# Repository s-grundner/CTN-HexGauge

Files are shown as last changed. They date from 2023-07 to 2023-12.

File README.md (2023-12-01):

# (EN) Hex Gauge

Customizable Automotive Gauge with CAN Bus and Integrated Inertial Measurement Unit

This is one of the initial Car Telemetry Networking (CTN) Projects.

The goal is to establish a Network of IoT devices for automotive telemtry capturing.

## Latest Revision

| Components Side | Display Side |
|-|-|
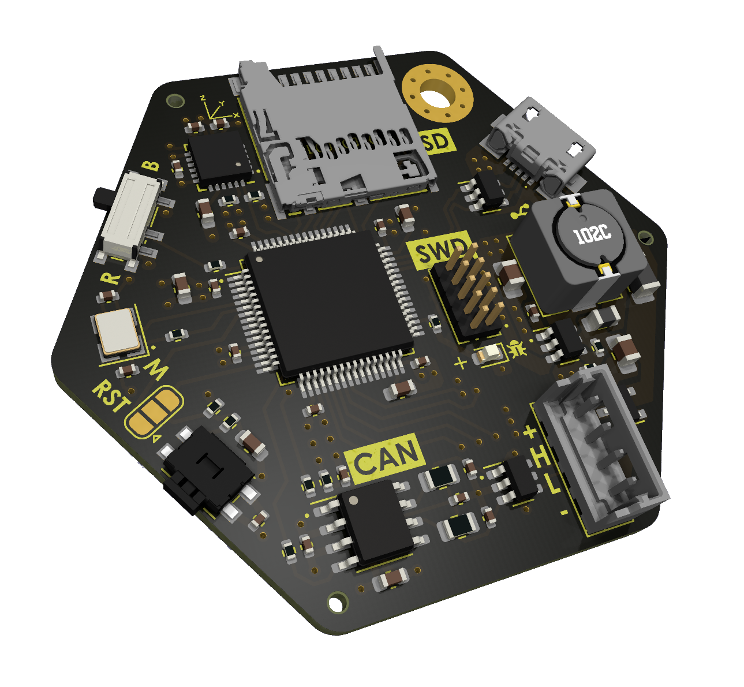
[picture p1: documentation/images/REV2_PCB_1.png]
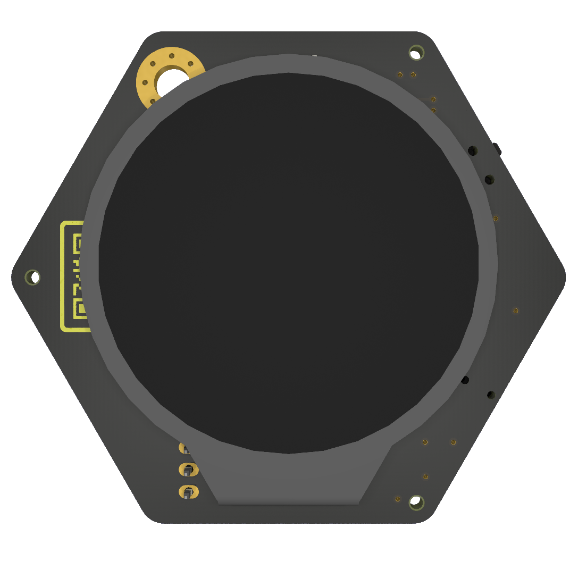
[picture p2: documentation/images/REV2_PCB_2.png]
|||

## Repository Structure

- [Documentation](/documentation/)
- [Manufacturing](/manufacturing/)
- [Simulations](/simulations/)
- [Source Code](/source/)

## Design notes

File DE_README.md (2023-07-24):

# (DE) Automobil Telemetrie Netzwerk

## Master Controller

| Nr  | Relevante Sensoren am Can bus | Instrumentenadresse/ID | Serienmäßig |
| --- | --- | --- | --- |
| 1 | Motordrehzahl | `0x` | ja |
| 2 | Geschwindigkeit | `0x` | ja |
| 3 | Reifendrehzahl | `0x` | ja |
| | | | |
| 4 | Batteriespannung | `0x` | ja |
| | | | |
| 5 | Öltemperatur | `0x` | ja |
| 6 | Kühlfl. Temperatur | `0x` | ja |
| 13  | Reifentemparatur | `0x` | nein |
| | | | |
| 7 | Öldruck | `0x` | ja |
| 8 | Bremsdruck | `0x` | ja |
| 9 | Kraftstoffdruck | `0x` | ja |
| | | | |
| 10  | Gaspedalposition | `0x` | ja |
| 11  | Gyroskop | `0x` | nein |

### Berechnungen

- CAN Bus Interface mit uC
  - Codes Auslesen
  - Ausgelesene Codes auf Armaturen schreiben

- Bremsschwund Erkennung und Berechnung
  - Vergleicht Bremsleitungsdruck mit Entschleunigung
  - Zeichnet Werte bei Verschiedenen Geschwindigkeiten auf und vergleicht

## Funktionseinheiten

### Reifentemaparatursensor

### Gyroskop

### Drehzahl LED-Leiste

## Modulare Hex Armaturen

- Ein zentrales Master Instrument, wo die Daten eingespeist werden (Drahtlos/Verdrahtet)
- Bus erweiterungen an 2/3/6 seiten des Hexagons
- Instrumentenadresse mit DIP-Schaltern einstellbar (SC18IS602B)
  - ID bestimmt angezeigte Daten
  - ID wird in SPI Chipselect konvertiert

## Retro Bargraphs

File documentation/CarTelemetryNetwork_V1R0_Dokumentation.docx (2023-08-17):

# Car Telemetry Network

# [Betreff]

Projekt Dokumentation – [DE]

Autor: Simon Grundner

V1R0

01/08/2023

# 1. H1

## 1.1 H2

### 1.1.1 H3

#### 1.1.1.1 H4

Simon Grundner – August 2023 I Dokumentation: RFID-Gwent

Repository: [Firmenadresse]

Dokumentation: Car Telemetry Network I Simon Grundner – 01/08/2023

Simon Grundner - 01/08/2023 I Dokumentation: Car Telemetry Network

Dokumentation: Car Telemetry Network 2 Simon Grundner – 01/08/2023

Simon Grundner – 01/08/2023 2 Dokumentation: Car Telemetry Network

https://github.com/s-grundner

Simon Grundner Projekt Dokumentation GitHub: s-grundner Car Telemetry Network 01/08/2023

https://github.com/s-grundner Inhaltsverzeichnis

Inhaltsverzeichnis https://github.com/s-grundner

https://github.com/s-grundner H1

H1 https://github.com/s-grundner

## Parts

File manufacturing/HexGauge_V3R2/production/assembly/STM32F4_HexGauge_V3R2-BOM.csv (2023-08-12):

Comment | Designator | Footprint | LCSC
2u2 | C1, C8, C12, C13, C17, C26 | Capacitor_SMD:C_0603_1608Metric | C23630
100n | C2, C3, C4, C5, C6, C7, C9, C16, C18, C20, C21, C22, C23, C24, C25 | Capacitor_SMD:C_0402_1005Metric | C1525
12p | C10, C11 | Capacitor_SMD:C_0402_1005Metric | C1547
10n | C19 | Capacitor_SMD:C_0402_1005Metric | C15195
White | D1 | LED_SMD:LED_0603_1608Metric | C2290
B5819W | D2 | Diode_SMD:D_SOD-123 | C8598
1A | F1 | Inductor_SMD:L_1206_3216Metric | C209741
100 @ 100MHz | FB1 | Inductor_SMD:L_0805_2012Metric | C1015
USB_B_Micro | J1 | SamacSys_Parts:101181920002LF | C397452
Micro_SD_Card | J3 | SamacSys_Parts:503398-1892 | C428492
Q_PMOS_GSD | Q1 | Package_TO_SOT_SMD:TSOT-23 | C15127
10k | R1 | Resistor_SMD:R_0402_1005Metric | C25744
10R | R2, R3 | Resistor_SMD:R_0402_1005Metric | C25077
47R | R4, R12, R14 | Resistor_SMD:R_0402_1005Metric | C25118
1k5 | R5, R6, R7 | Resistor_SMD:R_0402_1005Metric | C25867
100k | R10, R16, R18 | Resistor_SMD:R_0402_1005Metric | C25741
56R | R13, R15 | Resistor_SMD:R_0805_2012Metric | C17757
SW_Panasonic_EVQPUC | SW1 | Button_Switch_SMD:Panasonic_EVQPUL_EVQPUC | C79174
SW_SPDT | SW2 | Button_Switch_SMD:SW_SPDT_PCM12 | C221841
STM32F405RGT6 | U1 | Package_QFP:LQFP-64_10x10mm_P0.5mm | C15742
SN65HVD230 | U3 | Package_SO:SOIC-8_3.9x4.9mm_P1.27mm | C12084
USBLC6-2 | U4, U6 | Package_TO_SOT_SMD:SOT-23-6 | C7519
MPU-6050 | U5 | Sensor_Motion:InvenSense_QFN-24_4x4mm_P0.5mm | C24112
25MHz 12pF | Y1 | Crystal:Crystal_SMD_3225-4Pin_3.2x2.5mm | C9006

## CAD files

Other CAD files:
manufacturing/HexGauge_V3R2/STM32F4_HexGauge_V3.dxf

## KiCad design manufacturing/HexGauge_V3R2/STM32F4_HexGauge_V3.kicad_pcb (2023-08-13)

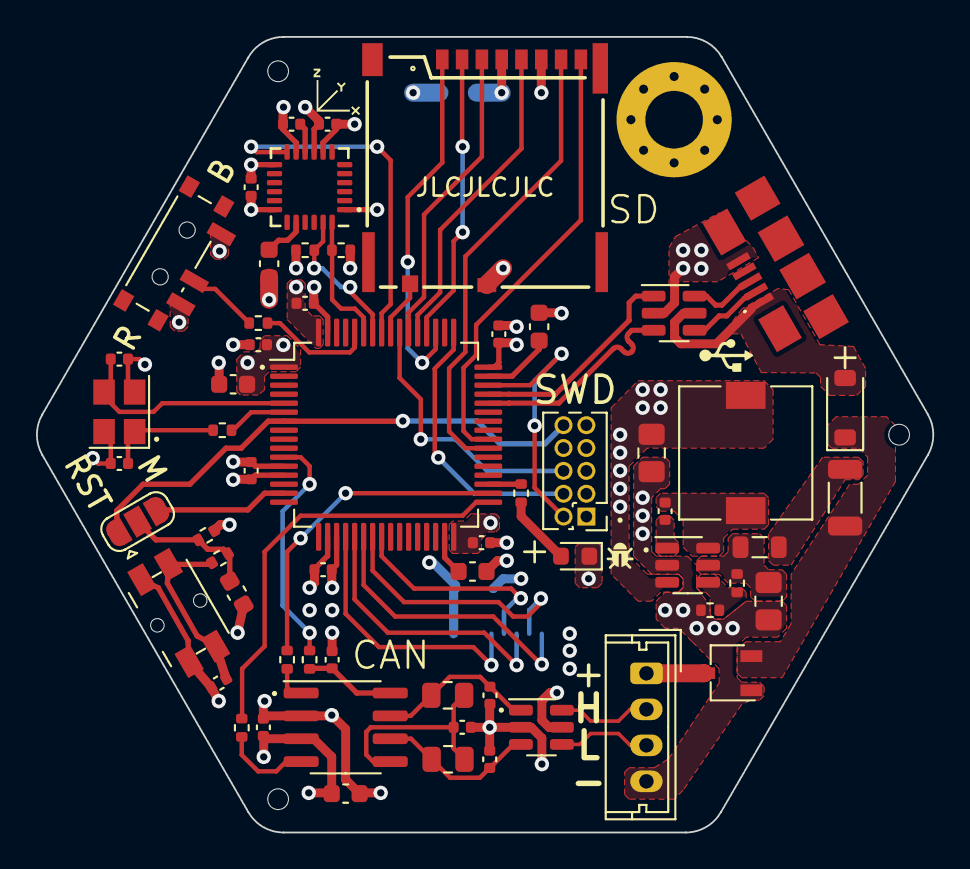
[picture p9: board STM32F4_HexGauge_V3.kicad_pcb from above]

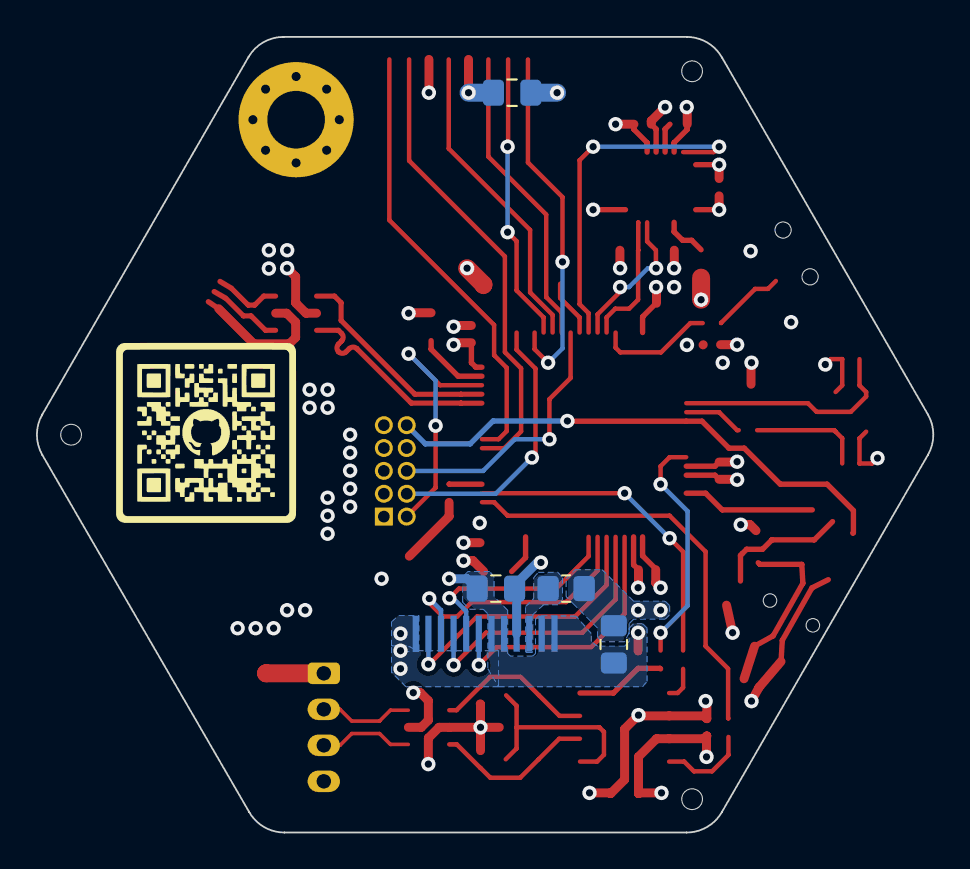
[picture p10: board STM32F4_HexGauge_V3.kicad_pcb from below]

Board: 4 copper layers, 49.8 x 44.2 mm, 69 parts (5 on the bottom side), 59 nets.

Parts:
C1, C8, C12, C13, C17, C26: 2u2; C_0603_1608Metric
C2, C3, C4, C5, C6, C7, C9, C16, C18, C20, C21, C22, C23, C24, C25: 100n; C_0402_1005Metric
C10, C11: 12p; C_0402_1005Metric
C14, C29: 2u2; C_0805_2012Metric_Pad1.18x1.45mm_HandSolder
C15: 10u; C_0805_2012Metric_Pad1.18x1.45mm_HandSolder
C19: 10n; C_0402_1005Metric
C27, C28: 100n; C_0805_2012Metric_Pad1.18x1.45mm_HandSolder
D1: White; LED_0603_1608Metric
D2: B5819W; D_SOD-123
F1: 1A; L_1206_3216Metric
FB1: 100 @ 100MHz; L_0805_2012Metric
H1: ER_TFT128-1
H2: MountingHole; MountingHole_3.2mm_M3_Pad_Via
H3, H4, H5: JLC_Tooling
J1: USB_B_Micro; 101181920002LF
J3: Micro_SD_Card; 503398-1892
J4: Conn_01x04_Pin; Molex_Micro-Latch_53253-0470_1x04_P2.00mm_Vertical
J5: Conn_02x05_Odd_Even; PinHeader_2x05_P1.27mm_Vertical
JP1: Jumper_3_Bridged12; SolderJumper-3_P1.3mm_Open_RoundedPad1.0x1.5mm
L1: 3u3; L_7.3x7.3_H4.5
Q1: Q_PMOS_GSD; TSOT-23
R1: 10k; R_0402_1005Metric
R2, R3: 10R; R_0402_1005Metric
R4, R12, R14: 47R; R_0402_1005Metric
R5, R6, R7: 1k5; R_0402_1005Metric
R10, R16, R18: 100k; R_0402_1005Metric
R13, R15: 56R; R_0805_2012Metric
R17: 10R; R_0805_2012Metric_Pad1.20x1.40mm_HandSolder
SW1: SW_Panasonic_EVQPUC; Panasonic_EVQPUL_EVQPUC
SW2: SW_SPDT; SW_SPDT_PCM12
U1: STM32F405RGT6; LQFP-64_10x10mm_P0.5mm
U2: LMR16006YQ3; SOT-23-6
U3: SN65HVD230; SOIC-8_3.9x4.9mm_P1.27mm
U4, U6: USBLC6-2; SOT-23-6
U5: MPU-6050; InvenSense_QFN-24_4x4mm_P0.5mm
Y1: 25MHz 12pF; Crystal_SMD_3225-4Pin_3.2x2.5mm

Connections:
+3V3: C1.1, C2.1, C3.1, C4.1, C5.1, C6.1, C7.1, C15.1, C17.1, C18.1, C19.1, C20.1, C27.1, C28.1, C29.1, H1.4 (VDD), J3.4 (VDD), J5.1, L1.2, R1.1, R6.2, R7.2, R17.1, SW2.1 (A), U1.1 (VBAT), U1.13 (VDDA), U1.19 (VDD), U1.32 (VDD), U1.48 (VDD), U1.64 (VDD), U2.3 (FB), U3.3 (VCC), U4.5, U5.8 (VLOGIC), U5.13 (VDD)
+12V: J4.1, Q1.3 (D)
/Connectors/D+: J1.3 (D+), U6.6
/Connectors/D-: J1.2 (D-), U6.4
/Connectors/TFT_LEDA: H1.3 (LEDA), R17.2
/MCU/BOOT0: R2.2, U1.60 (BOOT0)
/MCU/DEBUG_LED: R5.2, U1.35 (PB14)
/MCU/HSE_IN: C10.1, U1.5 (PH0), Y1.3
/MCU/HSE_OUT: R4.2, U1.6 (PH1)
/MCU/VCAP_1: C12.1, U1.31 (VCAP_1)
/MCU/VCAP_2: C13.1, U1.47 (VCAP_2)
/MCU/XTAL_IN: C11.1, R4.1, Y1.1
/PMU/BUCK_BST: C16.1, U2.1 (CB)
/PMU/BUCK_EN: R10.2, R18.1, U2.4 (~SHDN)
/PMU/BUCK_IN: C14.1, FB1.2, R10.1, U2.5 (VIN)
/PMU/BUCK_OUT: C16.2, L1.1, U2.6 (SW)
/PMU/POST_FUSE: F1.2, FB1.1
/PMU/POST_POL: D2.1 (K), F1.1, Q1.2 (S)
/Sensors/CAN+: C21.1, R13.2, U3.7 (CANH), U4.1
/Sensors/CAN-: C23.2, R15.1, U3.6 (CANL), U4.3
/Sensors/CAN_RS: C24.1, R16.2, U3.8 (Rs)
/Sensors/VREF: C22.1, R13.1, R15.2, U3.5 (Vref)
BTN: JP1.3 (B), U1.15 (PA1)
CAN_CONN+: J4.2, U4.6
CAN_CONN-: J4.3, U4.4
CAN_RX: R14.1, U1.33 (PB12)
CAN_SC: R16.1, U1.11 (PC3)
CAN_TX: R12.1, U1.34 (PB13)
GND: C1.2, C2.2, C3.2, C4.2, C5.2, C6.2, C7.2, C8.2, C9.2, C10.2, C11.2, C12.2, C13.2, C14.2, C15.2, C17.2, C18.2, C19.2, C20.2, C21.2, C22.2, C23.1, C24.2, C25.2, C26.2, C27.2, C28.2, C29.2, D1.1 (K), H1.1 (GND), H1.2 (LEDK), H1.5 (GND), H1.6 (GND), H1.12 (GND), J1.5 (GND), J3.6 (VSS), J3.10 (SHIELD), J4.4, J5.3, J5.5, J5.9, Q1.1 (G), R18.2, SW1.1, SW2.3 (C), U1.12 (VSSA), U1.18 (VSS), U1.63 (VSS), U2.2 (GND), U3.2 (GND), U4.2, U5.1 (CLKIN), U5.9 (AD0), U5.11 (FSYNC), U5.18 (GND), U6.2, Y1.2, Y1.4
IMU_INT: U1.57 (PB5), U5.12 (INT)
IMU_SCL: R6.1, U1.58 (PB6), U5.23 (SCL)
IMU_SDA: R7.1, U1.59 (PB7), U5.24 (SDA)
NRST: J5.10, JP1.1 (A), U1.7 (NRST)
unnamed: C9.1, R3.2, SW1.2
unnamed: D1.2 (A), R5.1
unnamed: C8.1, JP1.2 (C), R1.2, R3.1
unnamed: R2.1, SW2.2 (B)
unnamed: R12.2, U3.1 (D)
unnamed: R14.2, U3.4 (R)
unnamed: C26.1, U5.20 (CPOUT)
unnamed: C25.1, U5.10 (REGOUT)
SD_CLK: J3.5 (CLK), U1.53 (PC12)
SD_CMD: J3.3 (CMD), U1.54 (PD2)
SD_DAT0: J3.7 (DAT0), U1.39 (PC8)
SD_DAT1: J3.8 (DAT1), U1.40 (PC9)
SD_DAT2: J3.1 (DAT2), U1.51 (PC10)
SD_DAT3: J3.2 (DAT3/CD), U1.52 (PC11)
SD_DET: J3.9 (DET), U1.56 (PB4)
SWCLK: J5.4, U1.49 (PA14)
SWDIO: J5.2, U1.46 (PA13)
SWO: J5.6, U1.55 (PB3)
TFT_CS: H1.8 (CS), U1.24 (PC4)
TFT_DC: H1.7 (DC), U1.20 (PA4)
TFT_MOSI: H1.10 (MOSI), U1.23 (PA7)
TFT_RST: H1.11 (RST), U1.22 (PA6)
TFT_SCK: H1.9 (SCK), U1.21 (PA5)
USB_D+: U1.45 (PA12), U6.1
USB_D-: U1.44 (PA11), U6.3
VBUS: D2.2 (A), J1.1 (VBUS), U6.5

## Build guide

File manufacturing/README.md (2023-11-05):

# Revision 0

| Components Side | Display Side |
|-|-|
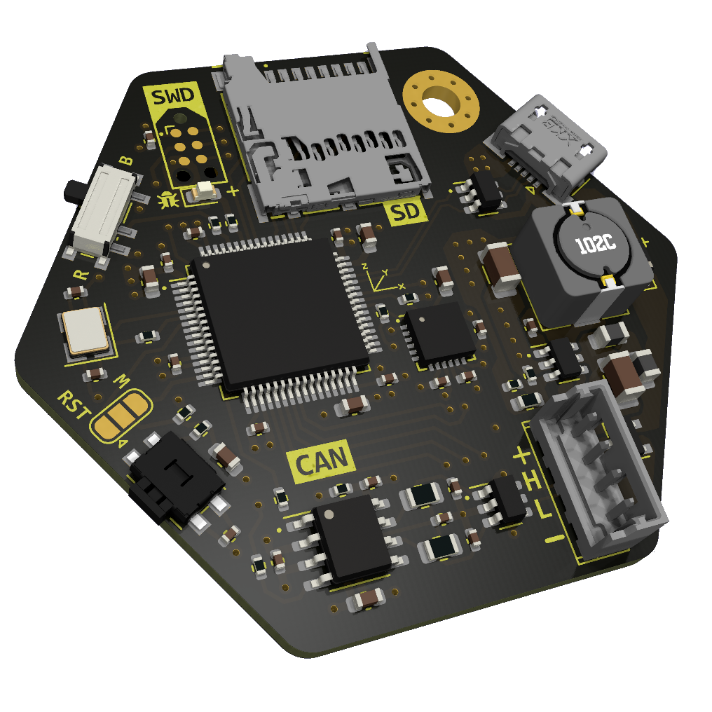
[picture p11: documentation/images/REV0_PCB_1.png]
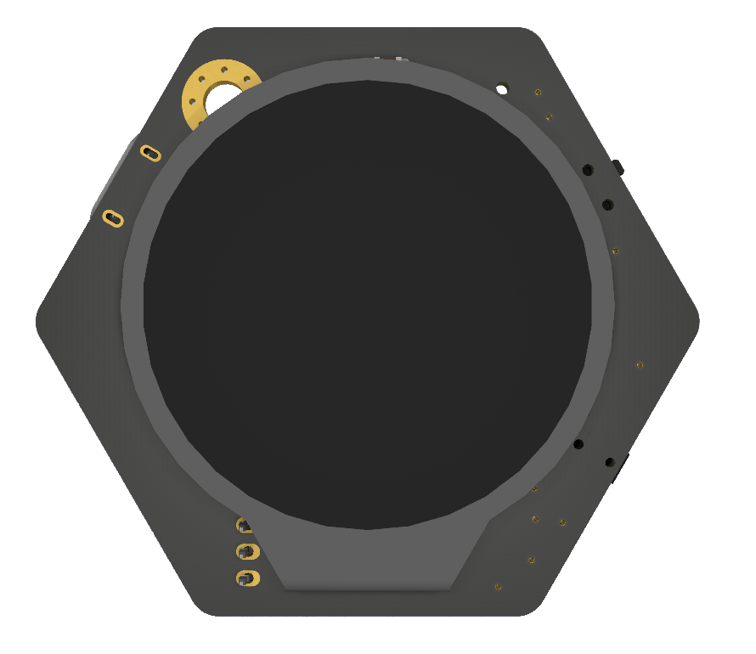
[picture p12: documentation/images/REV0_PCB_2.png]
|||

Features:

- SD Card with SPI Mode
- IMU on I2C3 SMBA
- TFT on SPI1

# Revision 1

| Components Side | Display Side |
|-|-|
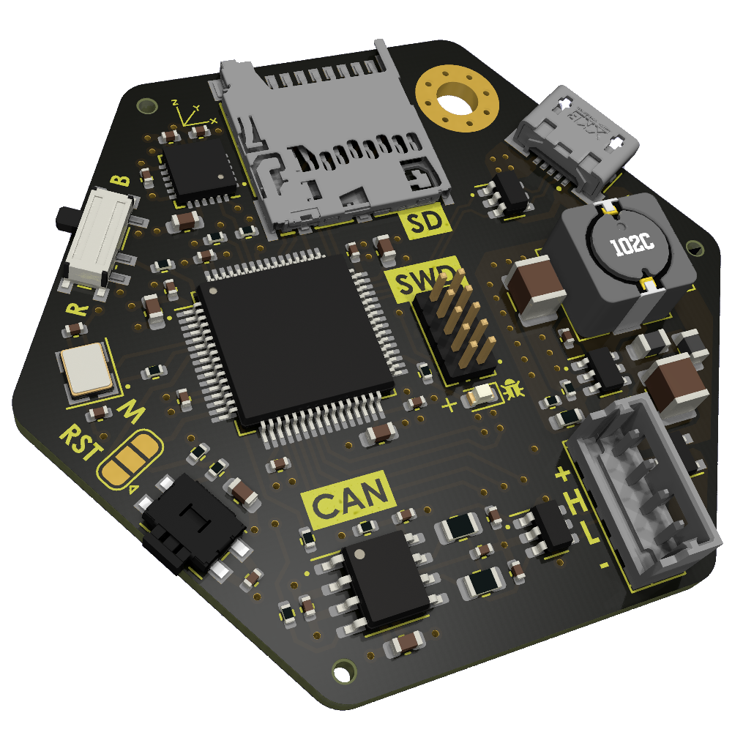
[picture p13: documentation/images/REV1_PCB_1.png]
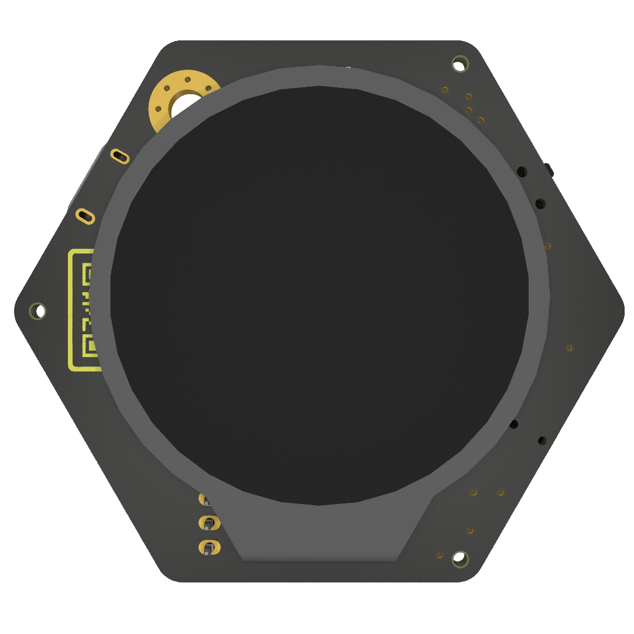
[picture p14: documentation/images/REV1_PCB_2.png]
|||

Changes:

- Fullspeed SDIO Interface
- IMU on I2C1 SMBA
- Optimized Buck Converter
- Slope Control for CAN Bus
- 10pin Header for Debugging
- Larger Silkscreen
- JLC Tooling Holes

# Revision 2

| Components Side | Display Side |
|-|-|
|||

Changes:

- Simple Switcher Buckconverter Update
- Optimized Traces for
  - IMU
  - SD Card
  - SWD Interface
  - TFT Display
- Reduced Overall costs

# Revision 3

> In Development

Changes:

- [x] SD Card Dataline Pullups
- [x] change Stack-Up -> Sig/Pwr, GND, GND, Sig/Pwr
- [x] Buck converter Thinner Feedback Trace

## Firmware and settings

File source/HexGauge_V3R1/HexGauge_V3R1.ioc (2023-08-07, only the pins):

Mcu.UserName=STM32F405RGTx
PA1.GPIO_Label=BTN_INT
PA1.Signal=GPXTI1
PA11.Signal=USB_OTG_FS_DM
PA12.Signal=USB_OTG_FS_DP
PA13.Signal=SYS_JTMS-SWDIO
PA14.Signal=SYS_JTCK-SWCLK
PA15.GPIO_Label=SDIO_DET
PA15.Signal=GPIO_Input
PA4.GPIO_Label=TFT_DC
PA4.Signal=GPIO_Output
PA5.Signal=SPI1_SCK
PA6.GPIO_Label=TFT_NRST
PA6.Signal=GPIO_Output
PA7.Signal=SPI1_MOSI
PB12.Signal=CAN2_RX
PB13.Signal=CAN2_TX
PB3.Signal=SYS_JTDO-SWO
PB5.Signal=I2C1_SMBA
PB6.Signal=I2C1_SCL
PB7.Signal=I2C1_SDA
PC10.Signal=SDIO_D2
PC11.Signal=SDIO_D3
PC12.Signal=SDIO_CK
PC3.GPIO_Label=CAN2_SLOPECTRL
PC3.Signal=GPIO_Output
PC4.GPIO_Label=TFT_NCS
PC4.Signal=GPIO_Output
PC8.Signal=SDIO_D0
PC9.Signal=SDIO_D1
PD2.Signal=SDIO_CMD
PH0-OSC_IN.Signal=RCC_OSC_IN
PH1-OSC_OUT.Signal=RCC_OSC_OUT

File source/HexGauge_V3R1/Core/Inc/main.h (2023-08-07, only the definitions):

#define CAN2_SLOPECTRL_Pin GPIO_PIN_3
#define CAN2_SLOPECTRL_GPIO_Port GPIOC
#define BTN_INT_Pin GPIO_PIN_1
#define BTN_INT_GPIO_Port GPIOA
#define BTN_INT_EXTI_IRQn EXTI1_IRQn
#define TFT_DC_Pin GPIO_PIN_4
#define TFT_DC_GPIO_Port GPIOA
#define TFT_NRST_Pin GPIO_PIN_6
#define TFT_NRST_GPIO_Port GPIOA
#define TFT_NCS_Pin GPIO_PIN_4
#define TFT_NCS_GPIO_Port GPIOC
#define SDIO_DET_Pin GPIO_PIN_15
#define SDIO_DET_GPIO_Port GPIOA

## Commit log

2023-07-30 Added Prototype Daughterboard Version 1
    with simple I2C to SPI conversion chip.
    SPI clock max 1.7MHz which is to slow to drive TFT displays:
    $\dfrac{250px \cdot 250px \cdot 16\frac{bit}{px}}{1.7 \cdot 10^{6}Hz}=0.588s = 1.7Hz$
    not including I2C Overhead
    [CTN.kicad_pcb, CTN.kicad_sch, bom.csv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]
2023-07-30 Added Prototype Daughterboard Version 2
    # Description
    SPI Chipselect Decoder with selectable CS Code
    Selected Logicfamily is LVC with very low $t_{pd}$ (few $ns$)
    CS Code selectable with 3 pol dip switch (latched on reset to avoid codebouncing)
    3 to 8 Demux + 8 to 1 Code selector combination not available in LVC.
    - Custom EXOR decoder with $t_{pd}$ of about 1 clock cycle on max SPI freq ($80MHz$)
    # Max Refresh rate
    One Display: $\dfrac{250px \cdot 250px \cdot 16\frac{bit}{px}}{80 \cdot 10^{6}Hz}=0.0125s = 80Hz$
    Max (8) Displays: $\dfrac{250px \cdot 250px \cdot 16\frac{bit}{px} \cdot 8}{80 \cdot 10^{6}Hz}=0.1s = 10Hz$
    No overhead due to Parallel CS Codelines and Sync
    [FastHexGauge.kicad_pcb, FastHexGauge.kicad_sch, PowerManagement.kicad_sch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]
2023-07-30 started Controller Motherboard
    [HexGaugeController.kicad_pcb, HexGaugeController.kicad_sch, PowerManagement.kicad_sch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]
2023-08-03 Updated Board to version 3
    [CTN.kicad_pcb, Connectors.kicad_sch, HexGaugeController.kicad_pcb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]
2023-08-03 Updated Board
    Added Mounting Hole and 3D Packages
    [Connectors.kicad_sch, STM32F4_HexGauge_V3.kicad_pcb]
2023-08-05 Updated Board and added Images
    [Connectors.kicad_sch, MCU.kicad_sch, STM32F4_HexGauge_V3.kicad_pcb]
2023-08-06 Updated Board do Revision 3
    SDIO Interface takes up I2C3 pin from the IMU.
    The IMU had to be configured to I2C1.
    SWD Connector position swapped with IMU on Layout
    Source has to be regenerated
    [Connectors.kicad_sch, IMU.kicad_sch, MCU.kicad_sch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]
2023-08-06 added old board
    [Connectors.kicad_sch, IMU.kicad_sch, MCU.kicad_sch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]
2023-08-06 V3R0 SPI SD Card Update
    [Connectors.kicad_sch, MCU.kicad_sch, STM32F4_HexGauge_V3.kicad_pcb]
2023-08-06 added new source
    Configured workspace and Low Level Drivers
2023-08-06 Cleaned up PCB
    [STM32F4_HexGauge_V3.kicad_pcb]
2023-08-07 Cleaned Up Schematic
    Added Blockdiagram
    Reannotated Symbols
    [Connectors.kicad_sch, IMU.kicad_sch, PMU.kicad_sch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]
2023-08-07 Updated Component Selection
    Better availability
    [MCU.kicad_sch, PMU.kicad_sch, STM32F4_HexGauge_V3.kicad_pcb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]
2023-08-08 Cost calculation
    Find extended parts on mouser
    [Connectors.kicad_sch, MCU.kicad_sch, PMU.kicad_sch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]
2023-08-08 Started Board Rev3
    Optimize Component Costs
    Smaller Buck Converter ->
    Move STM32 3mm to the right to simplify SD Card, IMU, TFT routing
    [Connectors.kicad_sch, IMU.kicad_sch, MCU.kicad_sch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]
2023-08-08 added Datasheets to components
    [PMU.kicad_sch, STM32F4_HexGauge_V3.kicad_pcb]
2023-08-08 upd board
    [MCU.kicad_sch, STM32F4_HexGauge_V3.kicad_pcb]
2023-08-12 Archived Old versions
    [CTN.kicad_pcb, CTN.kicad_sch, Connectors.kicad_sch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]
2023-08-12 FInalised Revision 2 Design
    [Connectors.kicad_sch, PMU.kicad_sch, STM32F4_HexGauge_V3.kicad_pcb]
2023-08-12 Gererated Gerber Files
    [STM32F4_HexGauge_V3-B_Cu.gbr, STM32F4_HexGauge_V3-B_Mask.gbr, STM32F4_HexGauge_V3-B_Paste.gbr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]
2023-08-12 upd fields
    [Connectors.kicad_sch, IMU.kicad_sch, MCU.kicad_sch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]
2023-08-13 rm prod_files
    regenerate when needed
    [STM32F4_HexGauge_V3-B_Cu.gbr, STM32F4_HexGauge_V3-B_Mask.gbr, STM32F4_HexGauge_V3-B_Paste.gbr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]
2023-08-13 upd board
    Small cleanups
    - better XTAL isolation
    - STM32: lower inductance supply
    [STM32F4_HexGauge_V3.kicad_pcb]

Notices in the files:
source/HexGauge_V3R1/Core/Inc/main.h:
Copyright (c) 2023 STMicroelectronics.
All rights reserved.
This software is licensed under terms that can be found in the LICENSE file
